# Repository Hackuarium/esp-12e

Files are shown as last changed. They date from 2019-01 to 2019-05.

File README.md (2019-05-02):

| GPIO  | | | | | | Arduino | |
| ----- | --- | --- | --- | --- | --- | --- | --- |
| 0 | | SPI_CS2 | | HIGH: normal, LOW: programming | LOW / HIGH | D3 | button LOW / BLK |
| 1 | | SPI_CS1 | U0_TXD  | | TX | D10 | TX |
| 2 | | | U1_TXD  | on boot HIGH for programming | HIGH | D4 | One WIRE (HIGH)  |
| 3 | | | U0_RXD  | | RX | D9 | RX |
| 4 | | | | | I2C | D2/SDA  | SDA |
| 5 | | | | | I2C | D1/SCL  | SCL |
| 6 | SDIO_CLK | SPI_CLK | | used to connect flash 4MB | reserved |
| 7 | SDIO_DATA0 | SPI_MISO  | | used to connect flash 4MB | reserved |
| 8 | SDIO_DATA1 | SPI_MOSI  | U1_RXD  | used to connect flash 4MB | reserved |
| 9 | SDIO_DATA2 | SPI_HD | HSPI_HD | used to connect flash 4MB | reserved |
| 10 | SDIO_DATA3 | SPI_WP | HSPI_WP | used to connect flash 4MB | reserved |
| 11 | SDIO_CMD | SPI_CS0 | | used to connect flash 4MB | reserved |
| 12 | MTDI | HSPI_MISO | | | MISO | D6 | PWM R |
| 13 | MTCK | HSPI_MOSI | U0_CTS  | | MOSI | D7 | PWM G |
| 14 | MTMS | HSPI_CLK  | | | CLK | D5 | PWM B |
| 15 | MTDO | HSPI_CS | U0_RTS  | on boot LOW for programming | LOW / CS | D8 | PWM W (LOW) |
| 16 | XPD_DCDC | | | sleep mode to EXT_RSTB (allow deep sleep) | RESET | D0 | RST |
| 17 | ADC | | | voltage 0—1.0V | Battery | A0 |
| RESET | | | | | | | Pull UP |

15: WS2812, adressable led

Read information on: https://www.kloppenborg.net/images/blog/esp8266/esp8266-esp12e-specs.pdf

Available pins: http://www.rabbithacks.com/esp8266/esp12-e-directly-usable-gpio-pins/

PWM on all the pins !
HSPI (screen or other): 12 13 14 15
PWM: R12 G15 B13
ADC: TOUT
I2C: SCL14 SDA2

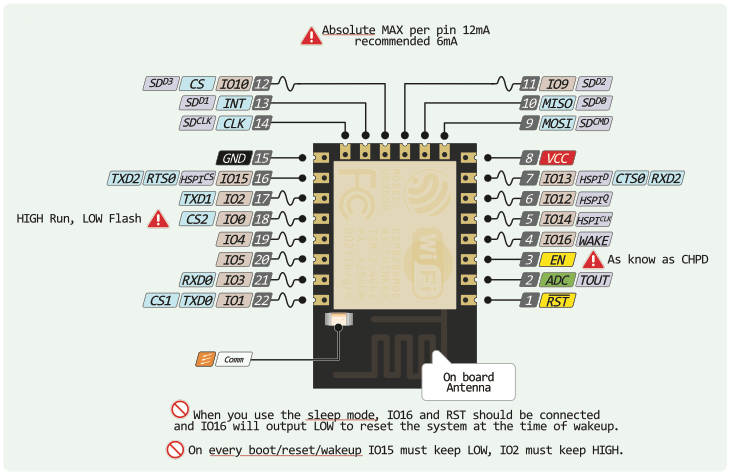
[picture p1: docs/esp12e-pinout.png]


## Flashing board ?

You need to maintain `SW2` while pressing `SW1` (reset) in order to set the ESP-12E in programing mode.

- https://hackaday.com/2015/03/18/how-to-directly-program-an-inexpensive-esp8266-wifi-module/
- https://easyeda.com/olegos76/ESP8266_arduino_IDE-d4457f9439fd4de7a8970ff36a4957d6
- https://www.instructables.com/id/3-Simple-Ways-of-Programming-an-ESP8266-12X-Module/
- https://www.codeproject.com/Articles/1152777/Programming-a-standalone-ESP-using-Arduino-IDE-and

## Programming from the arduino a nodeMcu

- https://www.instructables.com/id/Quick-Start-to-Nodemcu-ESP8266-on-Arduino-IDE/
- https://www.instructables.com/id/ESP8266-controlling-Neopixel-LEDs-using-Arduino-ID/

## MQTT+Node-RED

https://randomnerdtutorials.com/esp8266-and-node-red-with-mqtt/

With SSL (secure)? :

https://medium.com/@flespi/how-to-connect-esp8266-to-secure-mqtt-broker-know-it-all-and-get-it-done-approach-c33b94f37d88

https://hackaday.io/project/163666-secure-esp8266-mqtt-poc/log/158992-secure-mqtt-broker-setup

## FreeRTOS

It seems impossible to program the ESP-12E with RTOS from the Arduino IDE.

The SDK is maintained by Expressif and it svailable on:

https://github.com/espressif/ESP8266_RTOS_SDK

You will also find on this page the instructions to install the SDK

## Functions

- RGBW
- PCA9685 + 4 x BSP75
- WS2812 : addressable led
- Luminosity: TCS3400 or VEML6040 or VEML7700
- Pressure: MS5637
- Humidity / Temperature: ChipCAP2 or Si7021
- Power monitoring

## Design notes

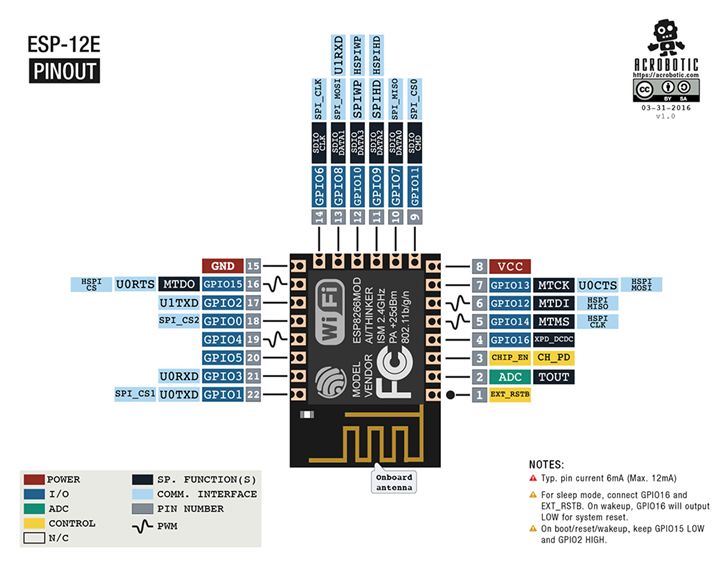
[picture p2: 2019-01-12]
docs/FIDTRK6JH8JBTII.LARGE.jpg

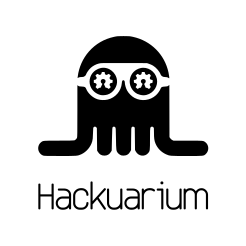
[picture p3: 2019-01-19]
kicad/hackuarium.png

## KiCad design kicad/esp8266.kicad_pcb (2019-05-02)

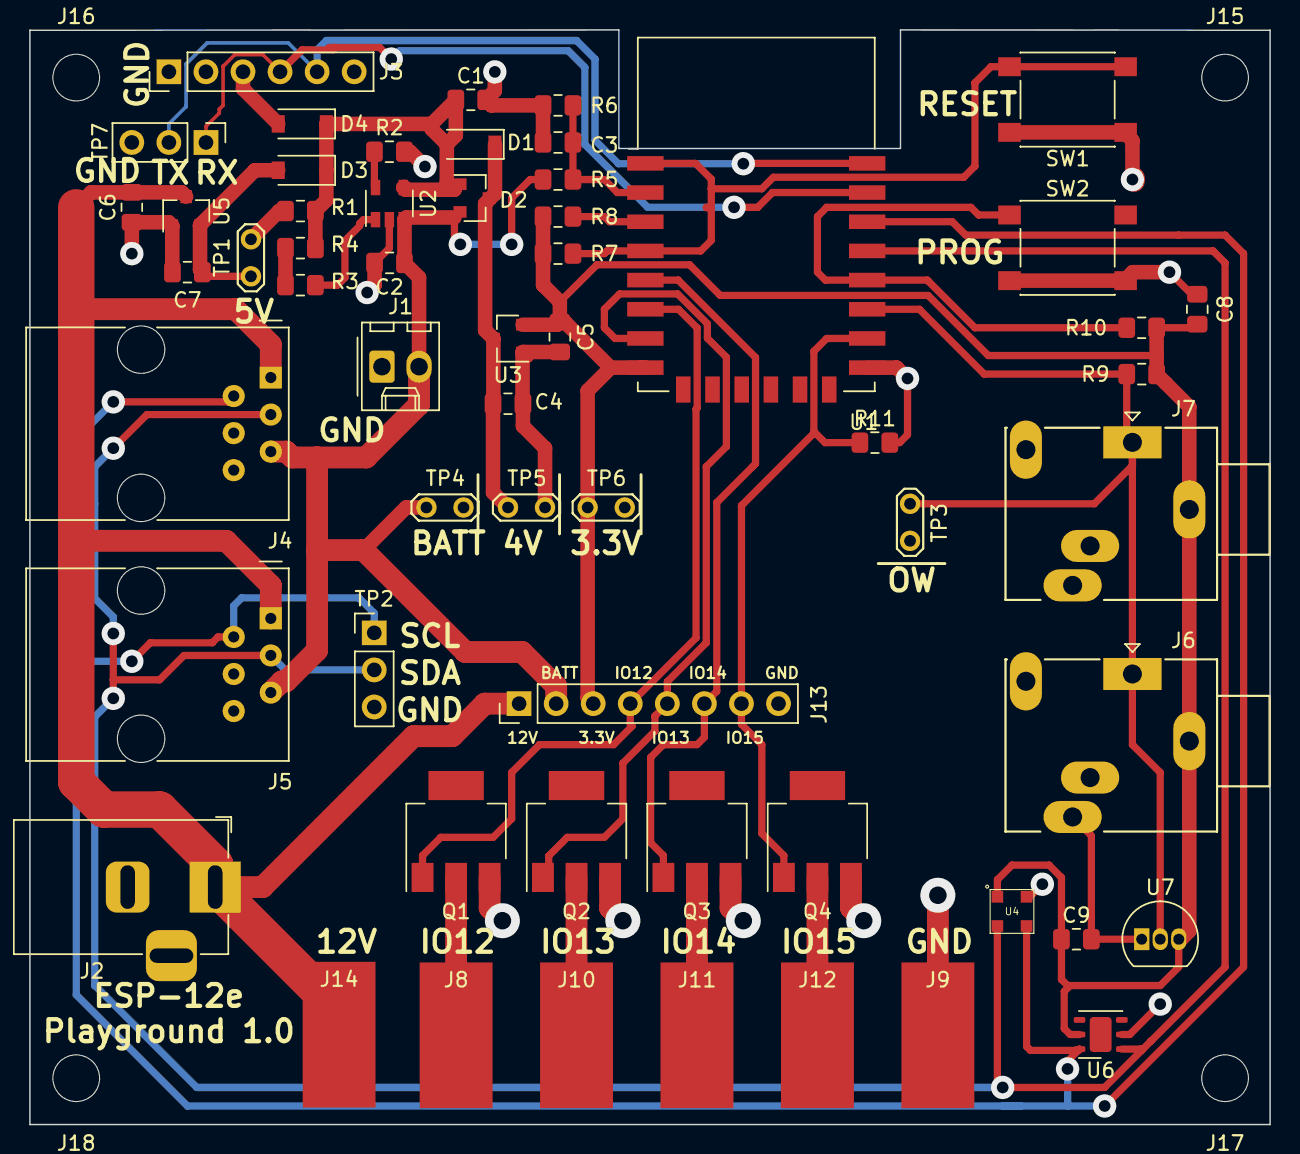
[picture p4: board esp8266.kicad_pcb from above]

Board: 2 copper layers, 85.0 x 75.0 mm, 62 parts (0 on the bottom side), 28 nets.

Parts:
C1, C2, C8, C9: 10uF; C_0805_2012Metric_Pad1.15x1.40mm_HandSolder
C3: 100nF; C_0805_2012Metric_Pad1.15x1.40mm_HandSolder
C4, C5, C6, C7: 1uF; C_0805_2012Metric_Pad1.15x1.40mm_HandSolder
D1, D3, D4: D_Schottky; D_SOD-123
D2: DMP1045U; SOT-23
J1: BATT; Molex_KK-254_AE-6410-02A_1x02_P2.54mm_Vertical
J2: 5 / 12V; BarrelJack_Horizontal
J3: CONN FT232RL; PinHeader_1x06_P2.54mm_Vertical
J4, J5: RJ12-I2C; RJ12_Amphenol_54601
J6, J7: Onewire; Jack_3.5mm_Ledino_KB3SPRS_Horizontal
J8: Red; SolderWirePad_1x01_SMD_5x10mm
J9: Pad; SolderWirePad_1x01_SMD_5x10mm
J10: Green; SolderWirePad_1x01_SMD_5x10mm
J11: Blue; SolderWirePad_1x01_SMD_5x10mm
J12: White; SolderWirePad_1x01_SMD_5x10mm
J13: IO_RGBW; PinHeader_1x08_P2.54mm_Vertical
J14: +12V; SolderWirePad_1x01_SMD_5x10mm
J15, J16, J17, J18: hole; MountingHole_3.2mm_M3
Q1, Q2, Q3, Q4: BSP75; SOT-223
R1: 100k; R_0805_2012Metric_Pad1.15x1.40mm_HandSolder
R2, R3, R4, R7, R8, R10, R11: 10k; R_0805_2012Metric_Pad1.15x1.40mm_HandSolder
R5: 1M; R_0805_2012Metric_Pad1.15x1.40mm_HandSolder
R6: 270k; R_0805_2012Metric_Pad1.15x1.40mm_HandSolder
R9: 4.7k; R_0805_2012Metric_Pad1.15x1.40mm_HandSolder
SW1: RESET; SW_SPST_PTS645
SW2: PROG; SW_SPST_PTS645
TP1: 5V; TestPoint_2Pads_Pitch2.54mm_Drill0.8mm
TP2: Test_i2C; PinHeader_1x03_P2.54mm_Vertical
TP3: OneWire; TestPoint_2Pads_Pitch2.54mm_Drill0.8mm
TP4: V_BAT; TestPoint_2Pads_Pitch2.54mm_Drill0.8mm
TP5: V_OUT; TestPoint_2Pads_Pitch2.54mm_Drill0.8mm
TP6: 3.3V; TestPoint_2Pads_Pitch2.54mm_Drill0.8mm
TP7: Test_UART; PinHeader_1x03_P2.54mm_Vertical
U1: ESP-12E
U2: MCP73831-2; SOT-23-5
U3: MCP1703-33; SOT-23
U4: MS5637
U5: MCP1703-50; SOT-23
U6: Si7020-A20; DFN-6-1EP_3x3mm_P1mm_EP1.5x2.4mm
U7: DS18B20; TO-92_Inline

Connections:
+3V3: C5.2, C8.1, C9.1, J6.S, J7.S, J13.3, R7.1, R8.1, R9.1, R10.1, TP6.1, U1.8, U3.2, U4.1, U6.5, U7.3
+12V: C6.2, J2.1, J4.1, J5.1, J13.1, J14.1, U5.3
+BATT: C2.1, D2.2, J1.2, J4.5, J5.5, J13.2, R5.1, TP4.1, U2.3
/ADC: C3.1, R5.2, R6.1, U1.2
/EN: R8.2, U1.3
/IO2: J6.T, J7.T, R9.2, TP3.1, U1.17, U7.2
/IO12: J13.4, Q1.1, U1.6
/IO13: J13.5, Q2.1, U1.7
/IO14: J13.6, Q3.1, U1.5
/IO15: J13.7, Q4.1, R11.1, U1.16
/MCP1703-33/VDD: C4.2, D1.1, D2.3, TP5.1, U3.3
/MCP1703-50/5.0V: C7.2, D3.2, TP1.1, U5.2
/MCP73831/VIN: C1.1, D1.2, D2.1, D3.1, D4.1, R1.1, R4.2, U2.4
/MCP73831/V_STATUS: R3.2, R4.1
/RST: R7.2, SW1.2, U1.1, U1.4
/RX: J3.4, TP7.1, U1.21
/SCL: J4.2, J5.2, TP2.1, U1.20, U4.3, U6.6
/SDA: J4.3, J5.3, TP2.2, U1.19, U4.2, U6.1
/TX: J3.5, TP7.2, U1.22
/VCC_FTDI: D4.2, J3.3
GND: C1.2, C2.2, C3.2, C4.1, C5.1, C6.1, C7.1, C8.2, C9.2, J1.1, J2.2, J3.1, J4.4, J4.6, J5.4, J5.6, J6.R, J7.R, J9.1, J13.8, Q1.3, Q2.3, Q3.3, Q4.3, R1.2, R2.2, R6.2, R11.2, SW1.1, SW2.2, TP1.2, TP2.3, TP3.2, TP4.2, TP5.2, TP6.2, TP7.3, U1.15, U2.2, U3.1, U4.4, U5.1, U6.2, U7.1
unnamed: J8.1, Q1.2
unnamed: J10.1, Q2.2
unnamed: J11.1, Q3.2
unnamed: J12.1, Q4.2
unnamed: R2.1, U2.5
unnamed: R3.1, U2.1
unnamed: R10.2, SW2.1, U1.18

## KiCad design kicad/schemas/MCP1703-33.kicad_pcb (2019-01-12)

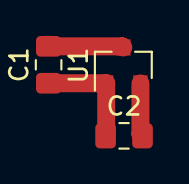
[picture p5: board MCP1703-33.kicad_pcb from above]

Board: 2 copper layers, 3 parts (0 on the bottom side), 3 nets.

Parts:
C1, C2: 1uF; C_0805_2012Metric_Pad1.15x1.40mm_HandSolder
U1: MCP1703A-3302_SOT23; SOT-23

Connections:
+3V3: C2.2, U1.2
GND: C1.1, C2.1, U1.1
VDD: C1.2, U1.3

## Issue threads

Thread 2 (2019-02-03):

switch button are not correctly connected !

lpatiny, 2019-02-03:

lpatiny, 2019-04-09:
Closed by cc1a9c224a835b2ab42f2356c35608d8a520c974

Closed 2019-04-09.

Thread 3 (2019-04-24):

Flashing board

oliemery, 2019-04-24:
Maybe we can avoid pressing buttons every time we upload sketches by using this ESP32 fix (to be tested before implementing on new PCB version): https://randomnerdtutorials.com/solved-failed-to-connect-to-esp32-timed-out-waiting-for-packet-header/

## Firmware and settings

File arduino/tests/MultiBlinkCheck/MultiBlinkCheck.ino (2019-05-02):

void setup() {
  Serial.begin(9600);
  //analogReference(); 
  pinMode(12, OUTPUT);
  pinMode(13, OUTPUT);
  pinMode(14, OUTPUT);
  pinMode(15, OUTPUT);
}

void loop() {
  Serial.println("Blinking IO 12 to 15 1sec ON, 1 sec OFF");
  digitalWrite(12, HIGH);
  digitalWrite(13, HIGH);
  digitalWrite(14, HIGH);
  digitalWrite(15, HIGH);
  delay(1000);
  digitalWrite(12, LOW);
  digitalWrite(13, LOW);
  digitalWrite(14, LOW);
  digitalWrite(15, LOW);
  delay(1000);
}

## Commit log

2019-01-12 add beginning of pcb
    [MCP73831.sch, esp8266.kicad_pcb, esp8266.sch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]
2019-01-13 improve kicad
    [MCP73831.sch, esp8266.sch, mcp1703-33.sch]
2019-01-15 add 18B20 on board
    [MCP73831.sch, esp8266.kicad_pcb, esp8266.sch]
2019-01-16 correst bsp75 footprint
    [MCP73831.sch, esp8266.kicad_pcb, esp8266.sch]
2019-01-17 add test points in kicad
    [MCP73831.sch, esp8266.kicad_pcb, esp8266.sch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]
2019-01-18 add more test points
    [esp8266.kicad_pcb, esp8266.sch, mcp1703-33.sch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]
2019-01-18 working on routing
    [MCP73831.sch, esp8266.kicad_pcb, esp8266.sch]
2019-01-19 first pcb v1.0
    [ESP8266-12E.igs, ESP8266-12E.obj, ESP8266-12E.stl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]
2019-01-19 final version of V100
    [esp8266-B.Cu.gbr, esp8266-B.Mask.gbr, esp8266-B.Paste.gbr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]
2019-01-20 add distances
    [esp8266.kicad_pcb, esp8266.sch]
2019-01-22 move 3d models to shared library
    [ESP8266-12E.igs, ESP8266-12E.obj, ESP8266-12E.stl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]
2019-01-22 move sub schemas
    [MCP1703-33.kicad_pcb, MCP1703-33.sch, MCP1703-50.sch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]
2019-01-22 pub back hackuarium logo on pcb
    [esp8266.kicad_pcb]
2019-02-03 improve label position
    [esp8266.kicad_pcb]
2019-04-09 fix resistor on IO15 and button
    [esp8266.kicad_pcb, esp8266.sch]
2019-05-02 Test to get battery level
2019-05-02 Test for blinking outputs 12-15 (Vin can be 5V or 12V according to the adapter plugged)
